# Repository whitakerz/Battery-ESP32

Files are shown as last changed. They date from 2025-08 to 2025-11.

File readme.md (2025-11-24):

# Home Assistant E-Ink Dashboard

A simple, battery-powered, Waveshare 2.9" e-ink display for Home Assistant, powered by ESPHome & ESP32.

## Project Overview

This project is a low-power, always-ready e-ink display for Home Assistant that runs on a Lolin D32 (ESP32) microcontroller. 
It was designed to display indoor and outdoor temperature, humidity, pressure, and weather conditions on a battery-powered device.

**Key features:**
- Battery and 5 V input voltage measurement using ADC (through a [resistor network](https://github.com/whitakerz/Battery-ESP32/blob/main/Resistor%20Network.txt)).
- Battery percentage estimation with nonlinear calibration
- Automatic day/night deep sleep control
- Home Assistant event logging for voltage and sleep cycles
- OTA updates and encrypted API communication
- Because existing code and enclosures did not meet my requirements, I combined multiple ESPHome projects, wrote custom configuration, 
and had a custom case designed on Fiverr.

## Hardware Used

- **Display:** Waveshare 2.9" E-Ink Display (V2, R2), 296x128 px, partial refresh, SPI interface
- **Microcontroller:** Lolin D32 (ESP32-based)
- **Battery:** Single-cell LiPo, monitored via ADC
- **Case:** Custom-designed and printed via Fiverr
- **Resistors:** Voltage divider networks for battery and 5V sensing
- **Miscellaneous:** 200Ω resistor for onboard LED, JST connectors, wiring

## Wiring Diagram

```
Power & Dividers (left)                             ESP32 (center)             E-Ink Display (right)
───────────────────────────                   ────────────────────────      ─────────────────────────────
          +5V supply                            ┌──────────────────┐            Waveshare 2.9" v2-r2
              |                                 │      ESP32       │              (3.3V logic)
           [20kΩ]                               │                  │
              |                                 │  GPIO18 ──────────────── CLK  ─────────────► SCK
          ──● Node A (GPIO36 sense) ────────────┤◄─ GPIO36 (ADC 5V)|        (SPI clock)
              |                                 │                  |
              |                                 │  GPIO23 ──────────────── MOSI ─────────────► DIN
              |                                 │                  |    (SPI data out)
              |                                 │                  |
            (series link)                       │  GPIO15 ───────────────── CS   ─────────────► CS
              |                                 │                  |
          ──● Node B (GPIO39 wake) ─────────────┤◄─ GPIO39 (wakeup)|
              |                                 │                  |
           [30kΩ]                               │  GPIO17 ───────────────── DC   ─────────────► D/C
              |                                 │                  |
            GND                                 │  GPIO16 ───────────────── RST  ─────────────► RST
                                                │                  |
      4.2V (LiPo)                               │  GPIO4  ◄──────────────── BUSY ─────────────◄ BUSY
              |                                 │                  |
           [36kΩ]                               │  3V3  ─────────────────── VCC  ─────────────► VCC (3.3V)
              |                                 │  GND  ─────────────────── GND  ─────────────► GND
          ──● Node C (GPIO32 batt) ─────────────┤◄─ GPIO32 (ADC batt)
              |                                 │                  |
           [100kΩ]                              │  GPIO22 ──► LED (Awake) ──►───┐
              |                                 │                  |       (LED)|
            GND                                 └──────────────────┘            └───[200Ω] GND

Legend:
  [value]   = resistor
  ● Node A  = divider tap for 5V sense (GPIO36)
  ● Node B  = divider mid / wake input (GPIO39)
  ● Node C  = divider tap for LiPo sense (GPIO32)
  LED       = “Awake LED” driven by GPIO22 (add a series resistor if needed)
```

GPIO39 doubles as a wake pin for deep sleep. GPIO22 drives an LED to indicate awake state. Both battery and 5V input are monitored via resistor dividers.

## Power Management

The display is battery-powered and relies on ESPHome's deep sleep functionality:
- Runs for ~1 minute per wake cycle (configurable)
- Daytime sleep of ~15 minutes between updates
- Night mode enters 8-hour deep sleep after 10 PM
- ESP32 is underclocked to 80 MHz for power savings

## Display Layout

- Top-left shows indoor temperature and humidity.
- Top-right contains a battery indicator with charging status.
- Middle section displays outdoor temperature, humidity, and pressure.
- Bottom section shows the timestamp of the last update.

## Software (ESPHome)

The configuration uses ESPHome to pull data directly from Home Assistant entities. Battery voltage is displayed using a nonlinear LiPo discharge curve. 
The code includes logic for day/night cycles, custom refresh rates, and battery percentage calculations.

## Case

Since no suitable enclosure existed, I commissioned a custom design via Fiverr. The case supports the display, microcontroller, and battery while remaining easy to open for maintenance. STL files are included in the repository.

## Credits and Inspiration

- ESPHome Feature Requests #1109
- kotope/esphome_eink_dashboard
- hanspeda/esphome_homeassistant_display
- Plawasan’s E-Ink Gist

## Getting Started

1. Clone this repository:
   ```bash
   https://github.com/whitakerz/Battery-ESP32.git
   ```
2. Flash the ESPHome config:
   ```bash
   esphome run battery-08-08-25.yaml
   ```
3. Connect the device to Home Assistant.
4. Print and assemble the custom case.

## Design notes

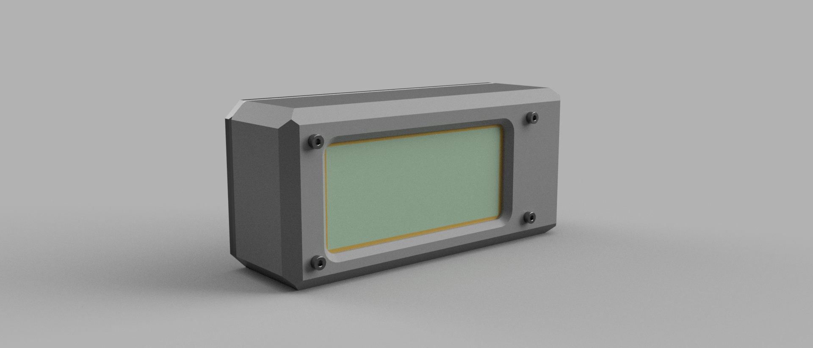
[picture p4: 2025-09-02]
Pictures/E ink display case2.png

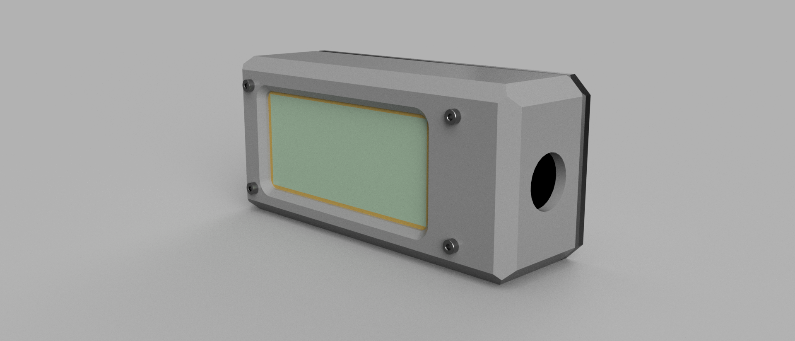
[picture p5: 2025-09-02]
Pictures/E ink display case-4.png

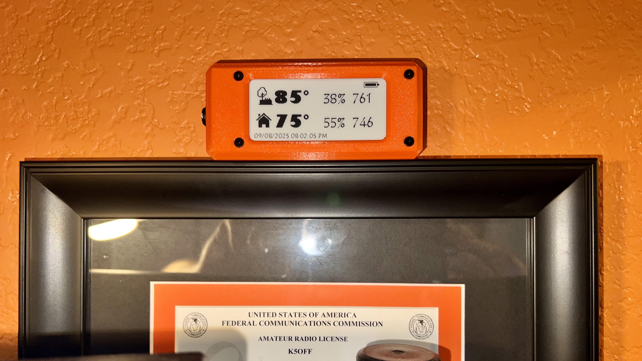
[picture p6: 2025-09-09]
Pictures/IMG_E1243.jpg

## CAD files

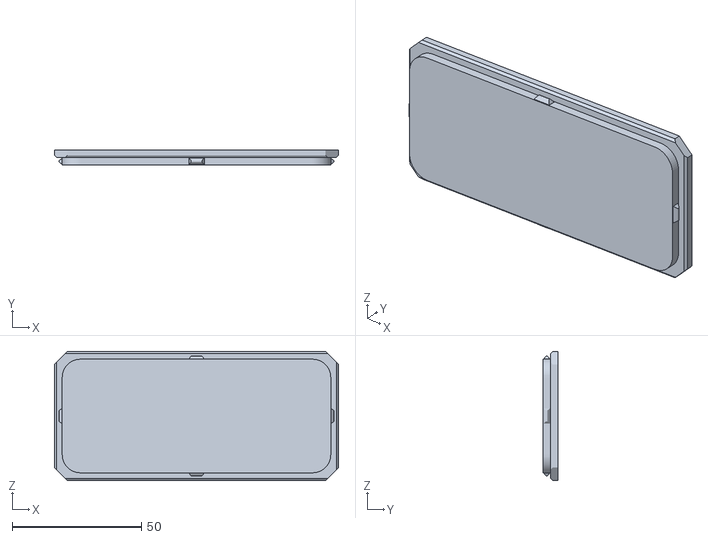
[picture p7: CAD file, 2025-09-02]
3DModel/backwithtextur.stl
110.0 x 6.00 x 50.0

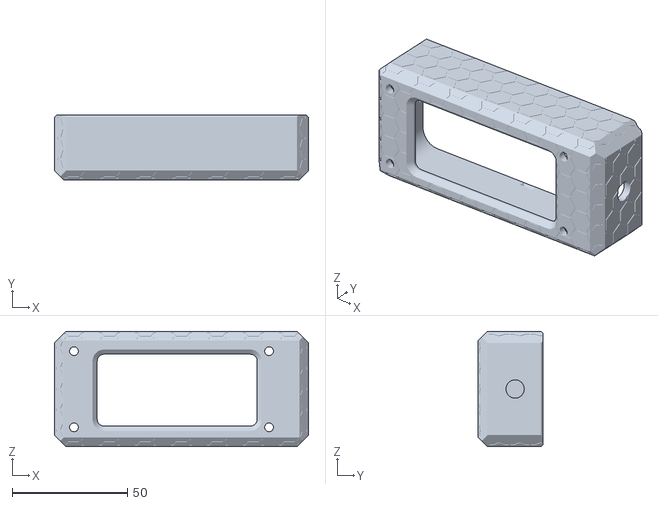
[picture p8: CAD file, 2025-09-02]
3DModel/frontwithtexture.stl
110.0 x 28.0 x 50.0

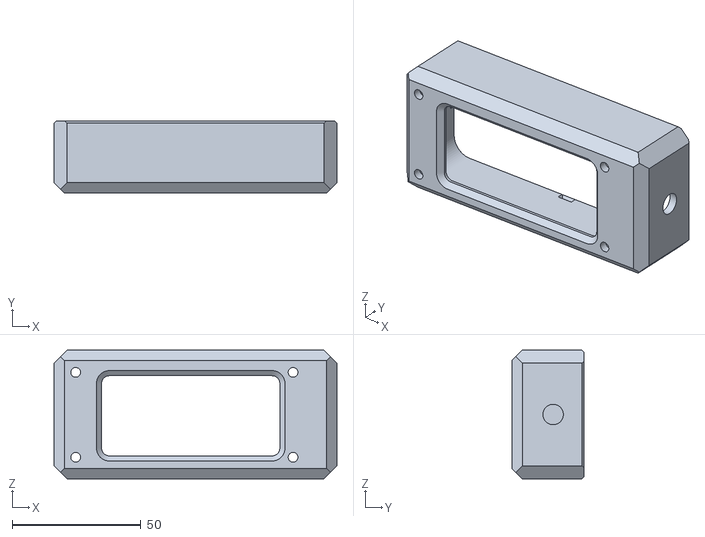
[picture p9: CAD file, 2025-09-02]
3DModel/front.stl
110.0 x 28.0 x 50.0

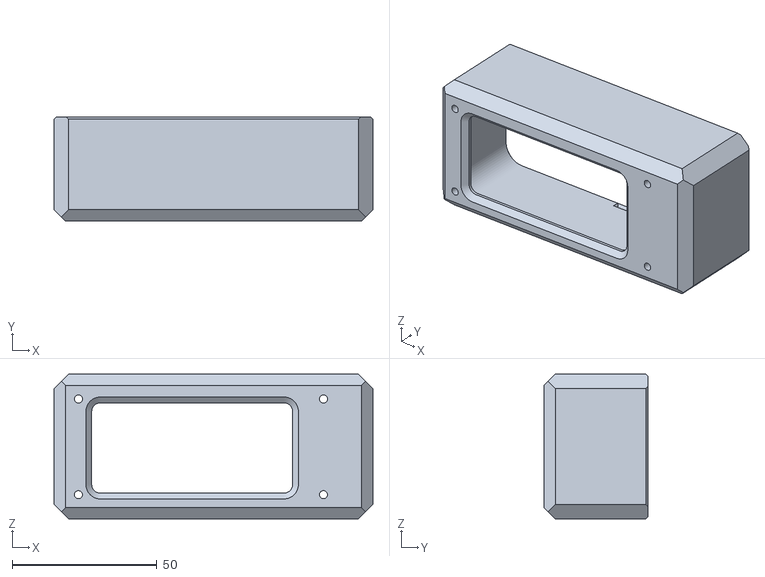
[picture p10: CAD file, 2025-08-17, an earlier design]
3DModel/Old Ones (Screen Hole in the Wrong Place)/front.stl
110.0 x 36.0 x 50.0

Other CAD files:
3DModel/back.stl
3DModel/Old Ones (Screen Hole in the Wrong Place)/back.stl
3DModel/E ink display case (1).f3d

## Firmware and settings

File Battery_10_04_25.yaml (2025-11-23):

#code parts used from
#https://github.com/esphome/feature-requests/issues/1109#issuecomment-1059808670
#https://github.com/kotope/esphome_eink_dashboard
#https://gist.github.com/Plawasan/4ae826b05aaa7812f3a191714ca47a50
#https://github.com/hanspeda/esphome_homeassistant_display.git
#chatgpt.com

substitutions:
  run_time: 1min #can be as long as needed to get data 
  sleep_time: 15min # normal sleep time
  night_sleep_time: 8h # 1st sleep time after 10pm

esphome:
  name: eink
  friendly_name: Eink
  on_boot:
    priority: 700
    then:
      - light.turn_on: awake_led
      - logger.log: "Boot: waiting for sensors to become ready before first draw, then sleep."
      - component.update: adc_5v_raw
      - component.update: adc_batt_raw
      - delay: 200ms

esp32:
  board: esp32dev
  framework:
    type: esp-idf
  cpu_frequency: 80MHz

logger:
  level: DEBUG

api:
  encryption:
    key: !secret batapi

ota:
  - platform: esphome
    password: "af02dabd1a628b113fb6ffc6c6a94c17"

wifi:
  ssid: !secret wifi_ssid
  password: !secret wifi_password
  manual_ip:
    static_ip: 192.168.7.103 # 👈 Replace with your desired static IP
    gateway: 192.168.7.1     # 👈 Replace with your router's IP
    subnet: 255.255.255.0    # 👈 Your network's subnet mask
  ap:
    ssid: "Battery Fallback Hotspot"
    password: "BDVDN7O0KT7E"

captive_portal:

spi:
  clk_pin: GPIO18
  mosi_pin: GPIO23

font:
  - file: "fonts/TEMPSITC.TTF"
    id: my_font
    size: 30
  - file: "fonts/GILSANUB.TTF"
    id: GILSANUB
    size: 38
  - file: "fonts/TEMPSITC.TTF"
    id: small
    size: 14

image:
  - file: "icons/partly_cloudy.bmp"
    id: icon_partlycloudy
    type: BINARY
    resize: 24x24
    invert_alpha: true
  - file: "icons/House.bmp"
    id: icon_inside
    type: BINARY
    resize: 34x34
    invert_alpha: false
  - file: "icons/Outside.bmp"
    id: icon_tree
    type: BINARY
    resize: 42x42
    invert_alpha: true

text_sensor:
  - platform: homeassistant
    id: forecast_condition
    entity_id: weather.forecast_home

sensor:
  - platform: homeassistant
    id: forecast_pressure
    entity_id: sensor.forecast_pressure_mmhg
  - platform: homeassistant
    id: humidity_outside
    entity_id: sensor.indoor_outdoor_meter_0a71_humidity
  - platform: homeassistant
    id: temperature_outside
    entity_id: sensor.calibrated_porch_temperature
  - platform: homeassistant
    id: pressure_printer
    entity_id: sensor.printer_barometer_pressure
  - platform: homeassistant
    id: humidity_printer
    entity_id: sensor.printer_barometer_humidity
  - platform: homeassistant
    id: temperature_printer
    entity_id: sensor.printer_barometer_temperature
  
  # ----- 5V sense (pre-divider) -----
  - platform: adc
    id: adc_5v_raw
    name: "ADC Pin Voltage (GPIO36)"
    pin: GPIO36
    attenuation: 12db
    update_interval: 5min
    accuracy_decimals: 3
    internal: true

  - platform: copy
    source_id: adc_5v_raw
    id: source_voltage
    name: "5V"
    unit_of_measurement: "V"
    accuracy_decimals: 2
    filters:
      - multiply: 1.8
    on_value:
      then:
        - lambda: |-
            static bool present = false;
            if (!present && x > 4.0) present = true;
            else if (present && x < 3.0) present = false;
            id(voltage_present).publish_state(present);

  # ----- LiPo battery voltage -----
  - platform: adc
    id: adc_batt_raw
    name: "ADC Pin Voltage (GPIO32)"
    pin: GPIO32
    attenuation: 12db
    update_interval: 5min
    accuracy_decimals: 3
    internal: true
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

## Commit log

2025-08-09 turn on led when awake
2025-08-09 conditional check before printing to screen
    add condition to display logic to only update when temperature is a valid number
2025-08-09 update interval when 5v present
2025-08-10 Testing Spacer
2025-08-10 before adding lipo sense
2025-08-10 After Battery Voltage
2025-08-10 Added Battery Indicator
    Removed Battery Voltage Text
2025-08-11 Moved Battery Indication & Changed Sleep to 15 min
2025-08-12 Update battery-08-08-25.txt
    Moved Forecast sensor to before screen update
2025-08-17 Added Images
    * added image files
    * added STL file for case
    * Added an MQTT Attempt to see if it saves battery power (unedited as of now)
    * removed old attempt at battery power
    [back.stl, front.stl]
2025-08-30 Added Battery2
2025-08-30 Added Schematic
2025-08-31 Reorganized Folders
    [back.stl, front.stl]
2025-09-02 Added 3d models
    [E ink display case (1).f3d, back.stl, backwithtextur.stl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]
2025-11-23 Update readme with resistor network link
    Added link to resistor network documentation for ADC input voltage measurement.
2025-11-23 Fix capitalization in resistor network link
